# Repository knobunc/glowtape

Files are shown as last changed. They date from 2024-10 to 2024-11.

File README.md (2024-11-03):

# Glowtape

Glow-in-the-dark display, 64 pixels wide, and as long as the memory allows :)

Using a UV LED pixel illumination from the [Glowxels](http://glowxels.org)
project.

[Note: this is pretty much work in progress and not the final version.]

To build: get all dependencies (if you're using nix, or the nix package manager,
it is simplest, they are in shell.nix).
Mostly openscad for the case, rp2040 sdk and toolchain for the firmware,
[bdfont.data](https://github.com/hzeller/bdfont.data) to compactly encode fonts
used in the firmware and the [gcode-cli](https://github.com/hzeller/gcode-cli)
used in the [set-time utility](./set-time.sh).

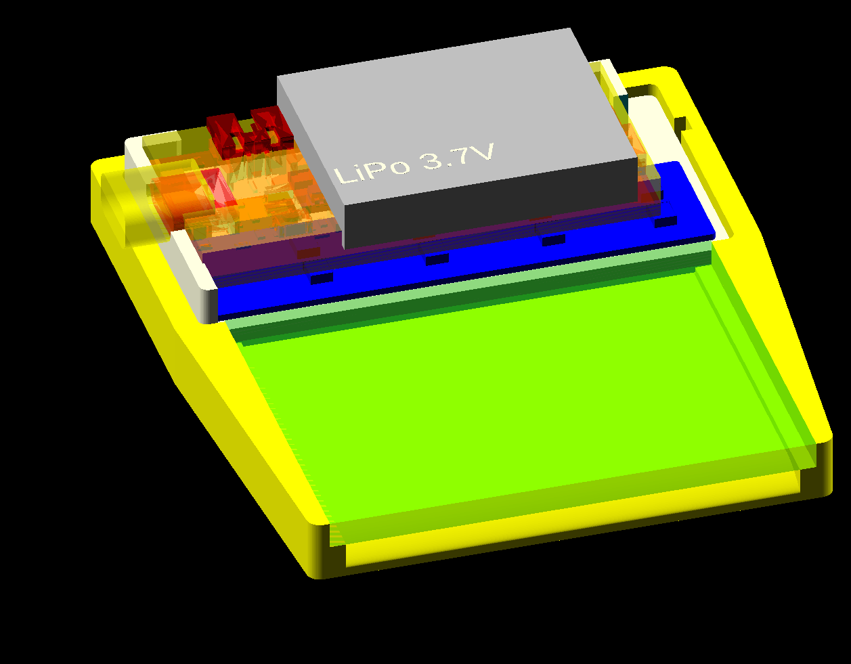
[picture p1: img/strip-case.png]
Render
  * [casing/](./casing/) for the OpenSCAD case 
  * [firmware/](./firmware/) contains the firmware.
  * [Gloxwls PCB](http://glowxels.org/). Check out the ['narrow'](https://github.com/hzeller/glowxels/tree/feature-20240902-narrow) feature branch.
  * [Encoder PCB](./pcb/encoder/) to pick up the encoder tape.
    Just type `make` to generate the fab files.
  * The sync-tape to be stuck to the back of the 50mm glow-in-dark
    tape: just `make` in the toplevel directory, it creates the PDF from
    the hand-written PostScript. Print on a high-resolution printer
    (e.g. 1200dpi) to minimize line-thickness variations due to aliasing.
  * Also some glow-in-dark tape that you can find in a hardware store, e.g.
    soemthing like [this](https://www.amazon.com/gp/product/B076BMQHXB)
    (no affiliation).

The RP2040 RTC does not remember its time after a reset (meh), so you need to
call the `./set-time.sh` script after a flash or reset/battery outage.

## Action shot

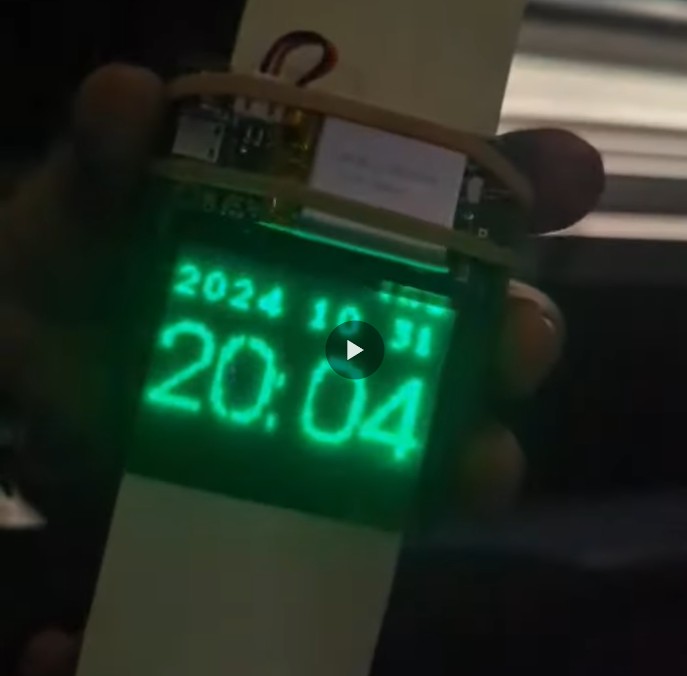
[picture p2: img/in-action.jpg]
Glow Watch (https://youtube.com/shorts/eKfHcU8QpuA)


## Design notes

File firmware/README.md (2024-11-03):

Firmware glowtape
=================

Makre sure you have all dependencies (on nix: get a nix-shell, otherwise get
pico SDK and compiler toolchain).

Then simply:

```
make
```

... and once Feather is connected with bootsel enabled

```
make flash
```

After the flash, the RP2040 RTC lost all time information, so you have to
set it again with

```
../set-time.sh
```

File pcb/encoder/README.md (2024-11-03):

Encoder PCB.

Note, this looks like one PCB, but you need to cut it in half in the middle at
the line.

Single-sided, so easy to etch at home.

For better contrast, I laser-cut a dark thin tape with two 0.4mm slots, 2mm
apart and taped on the photo transistor.

The strip-pattern is picked up with one photo transistor picking up a dark
strip, the other the light strip. When the tape is moved, the light conditions
swap. So the differntial pick-up makes it resilient to environment light
conditions as there does not need to be a fixed cut-off.

Choose resistors as needed; For `R9` LED, 82Ω was used. The `R1`, `R2` photo
transistor resistors, 2.7kΩ, `R5`: 10kΩ, and `R6`, which makes the whole
circuit a Schmitt Trigger for confident switch detection, somehing like 180kΩ.

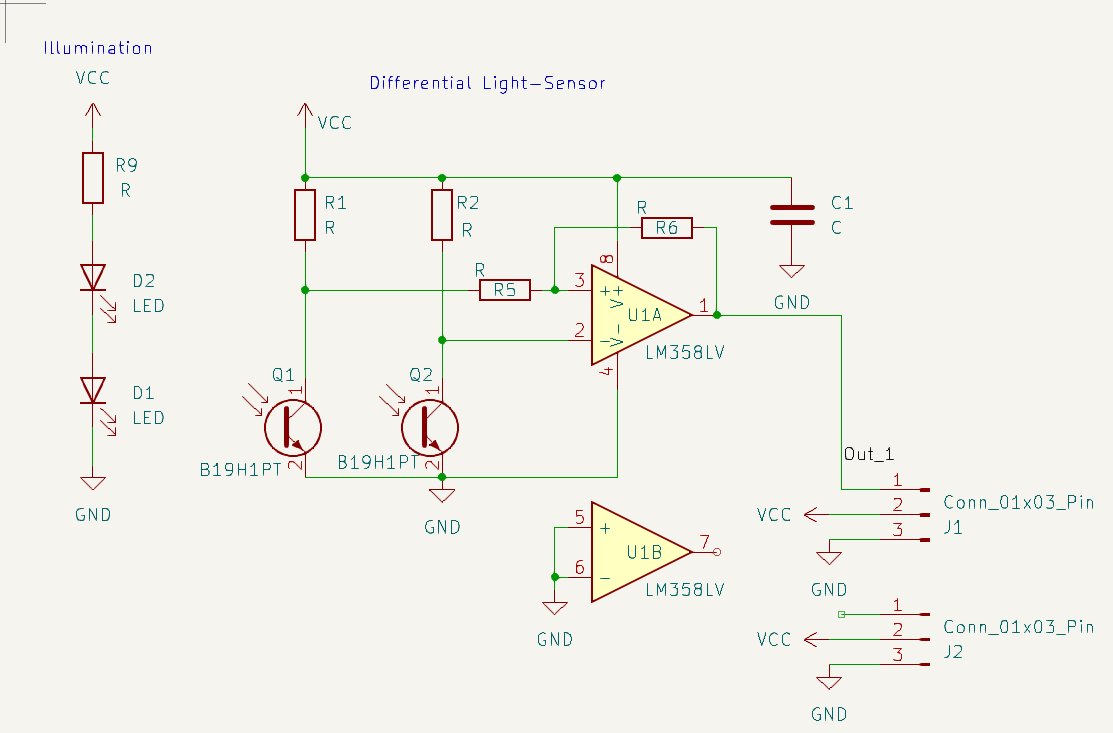
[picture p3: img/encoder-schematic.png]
Schematic


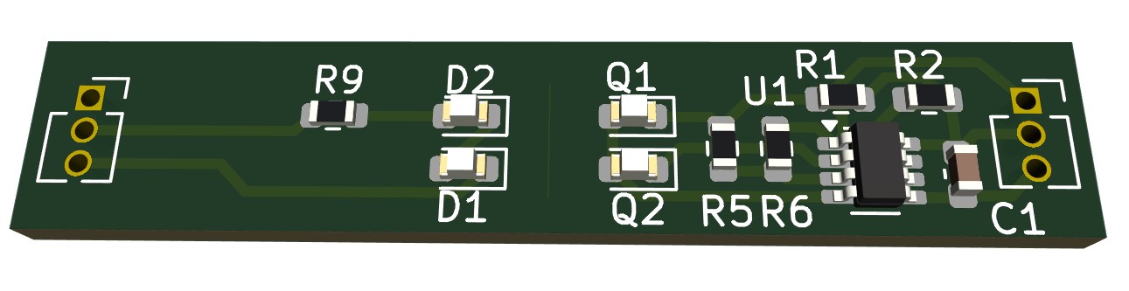
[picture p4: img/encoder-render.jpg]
Render


Here, a home-made isolation etch:

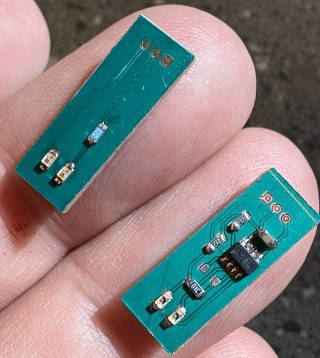
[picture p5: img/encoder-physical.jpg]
Physical


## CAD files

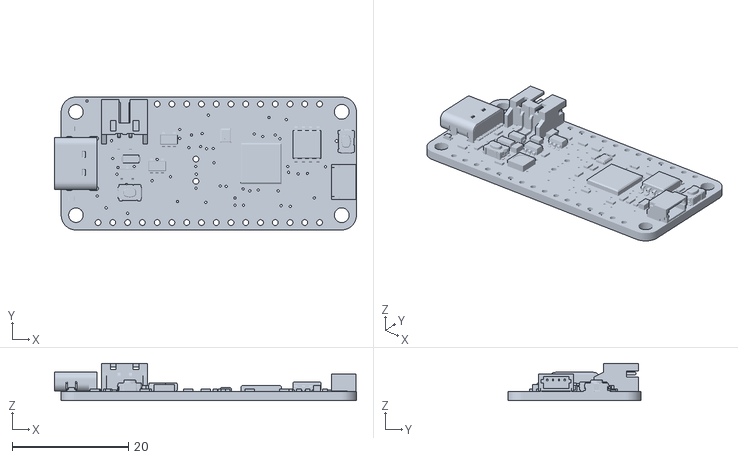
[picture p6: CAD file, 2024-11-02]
casing/Feather-rp2040.stl
51.9 x 22.9 x 6.37

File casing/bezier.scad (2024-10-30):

$fn=90;
e=0.01;

function _cubic_bazier_point(start, c1, c2, finish, t) =
  let (
    u = 1.0 - t,
    tt = t * t,
    uu = u * u
  )
  (u*uu) * start +
  3.0 * uu * t * c1 +
  3.0 * u * tt * c2 +
  (t*tt) * finish;

function cubic_bezier(start, c1, c2, finish, count=50) =
  [ for (t = [0 : 1/count : 1]) _cubic_bazier_point(start, c1, c2, finish, t) ];

module bezier_polygon(start, c1, c2, finish, count=100, visualize_cp=false) {
  polygon(cubic_bezier(start, c1, c2, finish, count));

  if (visualize_cp) {
    color("red") translate(c1) circle(r=0.2);
    color("green") translate(c2) circle(r=0.2);
  }
}

module viz_controlpoint(col, point, cp) {
  hull() {
    translate(point) circle(r=0.01);
    translate(cp) circle(r=0.01);
  }
  color(col) translate(cp) circle(r=0.1);
}

module viz_vertex(start, c1, c2, finish) {
  viz_controlpoint("red", start, c1);
  viz_controlpoint("green", finish, c2);
}

// One control point per point: Except for the last, they represent
// the first control-point after the point (the second control point is
// dereived from the _next_ segment, but pointing backwards, creating smooth
// curves.
module cubic_spline(points, cps,
		    extrude=-1, count=50,
		    show_controlpoints=false,
		    just_show_polygon=false) {
  effective_cps = (just_show_polygon || !cps) ? points : cps;
  assert(len(points) >= 2, "Need to have at least twp points");
  assert(len(points) == len(effective_cps),
	 "There needs one control point per point");
  second_to_last = len(points) - 1;
  list = [ for (i = [0:1:second_to_last-e])
      each cubic_bezier(points[i],
			effective_cps[i],
			i < second_to_last-1
			? points[i+1]-(effective_cps[i+1] - points[i+1])
			: effective_cps[i+1],
			points[i+1]) ];
  if (extrude > 0) {
    linear_extrude(height=extrude) polygon(list);
  } else {
    polygon(list);
  }

  if (show_controlpoints) {
    for (i = [0:1:second_to_last-e]) {
      viz_vertex(points[i], cps[i],
		 i < second_to_last-1
		 ? points[i+1]-(cps[i+1] - points[i+1])
		 : cps[i+1],
		 points[i+1]);
    }
  }
}

module place_along_curve(start, c1, c2, finish, at_fraction) {
  // Position
  pos = _cubic_bazier_point(start, c1, c2, finish, at_fraction);

  // Angle
  d0  = _cubic_bazier_point(start, c1, c2, finish, at_fraction - 0.01);
  d1  = _cubic_bazier_point(start, c1, c2, finish, at_fraction + 0.01);
  diff = d1 - d0;
  angle = atan2(diff.y, diff.x);

  translate([pos.x, pos.y, 0]) rotate([0, 0, angle]) children();
}


module test1() {
  cubic_spline(points=[  [0, 0], [1, 2], [3, 0]  ],
	       cps=[  [-1, 1], [2, 2], [4, 1]    ],
	       show_controlpoints=true);
}

module test2() {
  color("red") bezier_polygon([-1, 0], [0, 1], [3, 1], [2, 0]);
  place_along_curve([-1, 0], [0, 1], [3, 1], [2, 0], $t) {
    translate([-0.5, 0, 0]) cube([1, 1, 1]);
  }
}

test2();

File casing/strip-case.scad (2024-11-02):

// Note, this still needs cleanup.

use <bezier.scad>

$fn=60;
e=0.01;

top_len=59;
window_width=53.9;
window_elevate=1+e;

tape_width=50.3;
tape_thick=0.25;
extra_width=6;

track_thick=3;
acrylic_len=40;
front_frame=2;
illuminator_len=28 + front_frame;

track_len=illuminator_len + acrylic_len + 3;

module rounded_cube(w=20, h=10, thick=1, r=0.5) {
  r=(r <= 0) ? e : r;
  dx=w/2-r;
  dy=h/2-r;
  hull() {
    translate([+dx, -dy, 0]) cylinder(r=r, h=thick);
    translate([+dx, +dy, 0]) cylinder(r=r, h=thick);
    translate([-dx, -dy, 0]) cylinder(r=r, h=thick);
    translate([-dx, +dy, 0]) cylinder(r=r, h=thick);
  }
}

module pocket_cube(c, r=0.3) {
  cube(c);
  cylinder(r=r, h=c[2]);
  translate([c[0], 0, 0]) cylinder(r=r, h=c[2]);
  translate([c[0], c[1], 0]) cylinder(r=r, h=c[2]);
  translate([0, c[1], 0]) cylinder(r=r, h=c[2]);
}

module usb() {
  rotate([0, -90, 0]) hull() {  // USB extension
    cylinder(r=1.65, h=10);
    translate([0, 6, 0]) cylinder(r=1.65, h=10);
  }
}

module rp2040_simple() {
  translate([-50.8/2, 0, 0]) cube([50.8, 23, 4.8]);
  hull() {
    translate([-22, 8.4, 3.1]) usb();  // actual location
    translate([-22, 8.4, 5]) usb();    // punch-out help
  }
}

module rp2040_board(extra=0) {
  render() color("#ff000070") translate([-50.8/2, 0, 0]) {
    cube([50.8, 23, 1.6]);  // board thicken
    if (false) translate([2, 8.4, 3.28]) rotate([0, -90, 0]) hull() {  // USB extension
      cylinder(r=1.65, h=10);
      translate([0, 6, 0]) cylinder(r=1.65, h=10);
    }
    difference() {
      import("Feather-rp2040.stl");
      //translate([6.5, 14, 3]) cube([9, 10, 7]);  // battery connector.
    }
  }
}

module glowxel_pcb() {
  color("#0000ffff") {
    translate([-75.6, 39+14.3, 0]) import("glowxels-small.stl");
    translate([0, 14.4/2-0.2, 0]) color("red") rounded_cube(55.6, 14.4, 3);
  }
}

module encoder_board(w, h) {
  color("purple") {
    translate([-w/2, -h/2, 0]) cube([w, h, 3]);
    translate([-6.3, 0, -1.8]) cylinder(r=2.5, h=2);  // viewport
    translate([w/2-3, -h/2, -2]) cube([3, h, 3]);  // Glue joint
    translate([w/2, -(h-1)/2, 0]) cube([2, h-1, 3]);  // Cable
  }
}

module sensor_locator() {
  translate([-3, 20, 0]) children();
}

module strip_led_light() {
  encoder_board(19.1, 6.8); // IR LED illumination
}

module strip_sensor() {
  w=19.7;
  h=7.4;
  translate([-w/2, -h/2, -2.7]) pocket_cube([w, h, 3]);  // hollow
  // bottom retainer
  translate([-(w-1)/2, -(h-1)/2, -track_thick-e]) cube([w-1, h-1, track_thick]);
  translate([w/2-e, -(h-1)/2, -1.5]) cube([2, h-1, 3]);  // Cable extract
  fudge_len=tape_width/2-1;
  translate([w/2-e, -2.5/2, -1]) cube([fudge_len, 2.5, 6]);  // Cable channel
}

module battery() {
  color("silver") cube([32.5, 25.5, 5.7]);
  translate([0.5, 4, 0]) linear_extrude(height=5.7+e) text("LiPo 3.7V", size=3);
}

module window(punch=0) {
  len=acrylic_len + punch;
  color("#00ff0040") translate([-window_width/2, -len, 0]) {
    cube([window_width, len, 3+punch]);
  }
}

module pcb_arrangement() {
  translate([0, front_frame, 0]) {
    translate([0.3, 0, 0.25]) glowxel_pcb();
    sensor_locator() translate([0, 0, +0.5]) strip_led_light();
    //sensor_locator() translate([0, 0, -tape_thick]) strip_sensor();
    translate([-2.5, 3, 4.5]) {
      rp2040_board();
      color("#ffff0070") rp2040_simple();
      translate([-10, -1, 3]) battery();
    }
  }
}

module track_bottom(l=0, r=track_len, b=-track_thick) {
  turn=b+1;
  cubic_spline(points=[  [l+0, b],   // start edge. +0=sharp edge
			 [l, b+1], [l+5, 0],

			 [r-5, 0], [r, b+1],
			 [r-0, b]
		      ],

	       cps = [   [l, b],
			 [l, turn+0.5], [l+5+2, 0],

			 [r-5+2, 0], [r, turn-0.5],
			 [r, b]
		     ],
	       extrude=tape_width,
	       show_controlpoints=false,
	       just_show_polygon=false);
}

module base_case_bottom(len=top_len, back=illuminator_len, height=2.5, extra=0) {
  translate([0, back/2, 0]) rounded_cube(len+extra, back+extra, height, r=1);
}

module base_case(len=top_len) {
  back=illuminator_len;
  render() translate([0, front_frame, 0]) difference() {
    intersection() {
      union() {
	translate([0, -front_frame, 0]) base_case_bottom(len, back);

	// Center rests
	translate([-20-1, 14.5, 0]) cube([7, 4, 5]);
	translate([+20-7-3, 14.5, 0]) cube([7, 4, 5]);

	// Side holders
	translate([-5, 0, 0]) translate([len/2-5, back-8-2, 0]) cube([5, 8, 8]);
	translate([-len/2, back-13.5-2, 0]) cube([6, 13.5, 8]);
	translate([-len/2, -front_frame, 0]) cube([1.8, illuminator_len, 8]);
	//translate([-len/2, illuminator_len-front_frame-1.5, 0]) cube([len, 1.5, 8]);
      }
      translate([0, -front_frame, 0]) base_case_bottom(len, back, 20);
    }
    translate([0, -front_frame, 0]) pcb_arrangement();
    translate([0, 6.6, -3]) {
      rounded_cube(w=54, h=9, r=2.5, thick=6);  // UV-window
    }
    translate([0, -1, 2.6]) sensor_locator() cube([60, 2, 10]);
  }
}

module ear() {
  cylinder(r=2, h=0.2);
}

module base_case_print() {
  base_case();
}

module side_wall(wall_height=4) {
  r=1.5;
  h=wall_height + track_thick;
  // The wider part for the illuminator.
  extra_wide=(top_len - tape_width)/2;

  hull() {
    translate([0, 0, -track_thick]) cube([e, track_len, h]);

    translate([r+1, r, -track_thick]) cylinder(r=r, h=h);
    translate([r, track_len-r, -track_thick]) cylinder(r=r, h=h);

    translate([r+extra_wide, acrylic_len, -track_thick]) cylinder(r=r, h=h);
    translate([r+extra_wide, track_len-r, -track_thick]) cylinder(r=r, h=h);
  }
}

module track_frame() {
  translate([-tape_width/2, -acrylic_len, 0]) {
    rotate([0, 0, 90]) rotate([90, 0, 0])  track_bottom();
  }
  translate([tape_width/2, -acrylic_len, 0]) side_wall();
  translate([-tape_width/2, -acrylic_len, 0]) scale([-1, 1, 1]) side_wall();
}

module track() {
  difference() {
    track_frame();
    translate([0, 0, tape_thick]) base_case_bottom(height=10, extra=0.4);
    translate([0, 0, window_elevate]) window(punch=1);
    sensor_locator() translate([0, front_frame, 0]) strip_sensor();
  }
}

module assembly() {
  color("yellow") track();
  translate([0, 0, tape_thick]) {
    base_case_print();
    pcb_arrangement();
  }
  translate([0, 0, window_elevate]) window();
}

assembly();

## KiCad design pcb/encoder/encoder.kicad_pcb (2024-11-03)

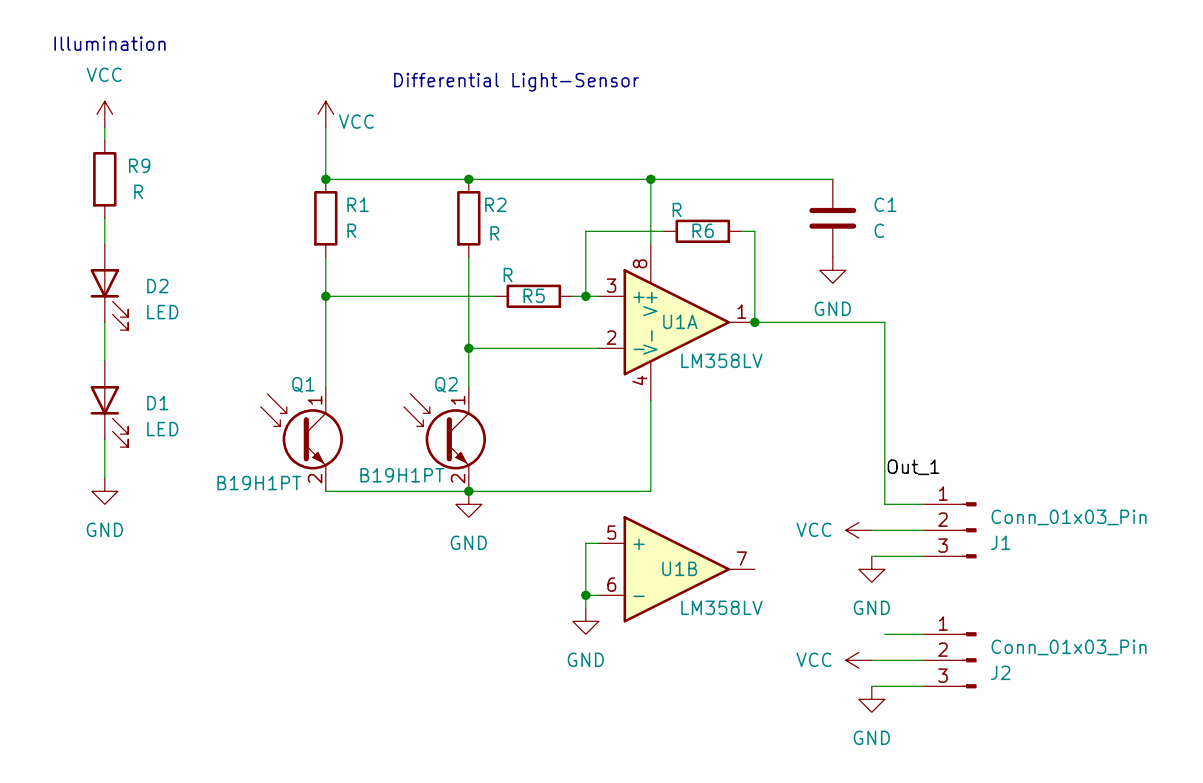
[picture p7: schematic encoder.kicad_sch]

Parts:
C1: C; C_0603_1608Metric
D1, D2: LED; LED_0603_1608Metric
J1, J2: Conn_01x03_Pin; PinSocket_1x03_P1.27mm_Vertical
Q1, Q2: B19H1PT; LED_0603_1608Metric
R1, R2, R5, R6, R9: R; R_0603_1608Metric
U1: LM358LV; SOT-23-8

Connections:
/Out_1: J1.1, R6.2, U1.1
GND: C1.2, D1.1 (K), J1.3, J2.3, Q1.2 (E), Q2.2 (E), U1.4 (V-), U1.5 (+), U1.6 (-)
unnamed: D1.2 (A), D2.1 (K)
unnamed: D2.2 (A), R9.2
unnamed: Q1.1 (C), R1.2, R5.1
unnamed: Q2.1 (C), R2.2, U1.2 (-)
unnamed: R5.2, R6.1, U1.3 (+)
VCC: C1.1, J1.2, J2.2, R1.1, R2.1, R9.1, U1.8 (V+)

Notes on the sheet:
Differential Light-Sensor
Illumination

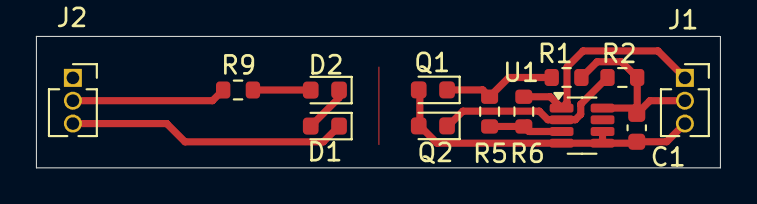
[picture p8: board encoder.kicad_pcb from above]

Board: 2 copper layers, 38.0 x 7.3 mm, 13 parts (0 on the bottom side), 8 nets.

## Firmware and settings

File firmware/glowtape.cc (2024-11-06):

#include <pico/types.h>

#include <cstdio>

#include "bdfont-support.h"
#include "button-counter.h"
#include "frame-printer.h"
#include "hardware/rtc.h"
#include "line-reader.h"
#include "strip-encoder.h"

// Generated font data
#include "font-6x9.h"
#include "font-large.h"
#include "font-message.h"
#include "font-timetext.h"

// Some demo bitmap content
#include "bitmap-contents.h"

// Time a single line is flashing the 405nm LEDs.
constexpr uint16_t kFlashTimeMillis = 5;

// GPIO where the input button lives. The Feather board has the BOOTSEL button
// connected to this GPIO.
constexpr int kButtonPin = 4;

constexpr int kSpiTxPin = 11;  // TX1, 10=sck1, 9=CS1

// A simple wrapper to emit bdfont text to out FramePrinter.
static void WriteText(FramePrinter *out, const struct FontData *font, int xpos,
                      int ypos, const char *print_text,
                      bool right_aligned = false, int extra_space = 0) {
  if (right_aligned) {
    for (const char *txt = print_text; *txt; ++txt) {
      auto g = bdfont_find_glyph(font, *txt);
      if (g) xpos -= g->width;
      xpos -= extra_space;
    }
  }
  for (const char *txt = print_text; *txt; ++txt) {
    int dx = 0;
    xpos += BDFONT_EMIT_GLYPH(
        font, *txt, false, { dx = 0; },
        {
          for (int i = 0; i < 8; ++i) {
            out->SetPixel(xpos + dx, stripe * 8 + ypos + i, b & (1 << i));
          }
          ++dx;
        },
        {});
    xpos += extra_space;
  }
}

void DrawTime(FramePrinter *out) {
  datetime_t now{};
  const bool time_valid = rtc_get_datetime(&now);
  if (!time_valid) {
    // RTC of rp2040 is a bit annoying, its content does not survive
    // resets. To be set with the set-time.sh script.
    WriteText(out, &font_6x9, 2, 0, "Set Time!");
    return;
  }
  const char *weekday = "-";
  switch (now.dotw) {
    case 0: weekday = "Sunday"; break;
    case 1: weekday = "Monday"; break;
    case 2: weekday = "Tuesday"; break;
    case 3: weekday = "Wednesday"; break;
    case 4: weekday = "Thursday"; break;
    case 5: weekday = "Friday"; break;
    case 6: weekday = "Saturday"; break;
  }
  WriteText(out, &font_6x9, 62, 0, weekday, true);

  char buffer[32];
  snprintf(buffer, sizeof(buffer), "%4d-%02d-%02d", now.year, now.month,
           now.day);
  WriteText(out, &font_6x9, 2, 10, buffer);

  snprintf(buffer, sizeof(buffer), "%02d:%02d", now.hour, now.min);
  WriteText(out, &font_timetext, 2, 22, buffer);
}

// Create content, derived from number of button presses before.
void CreateContent(FramePrinter *out, int what_content) {
  enum Content {
    kTime,  // Default: no button presses
    kName,
    kJollyWrencher,
    kSupercon,
    kProject,
  };

  out->StartNewImage(ScreenAspect::kAlongWidth);

  if (what_content == kJollyWrencher) {
    for (uint64_t row : kJollyWrencherBitmap) {
      out->push_back(row);
    }
    return;
  }

  if (what_content == kName) {
    WriteText(out, &font_message, 2, 0, "Henner", false, 2);
    WriteText(out, &font_message, 62, 15, "Zeller", true, 2);
    return;
  }

  if (what_content == kSupercon) {
    out->StartNewImage(ScreenAspect::kAlongLength);
    WriteText(out, &font_large, 0, 8, "Supercon 8");
    return;
  }

  if (what_content == kProject) {
    for (uint64_t row : kProjectQRBitmap) {
      out->push_back(row);
    }
    return;
  }

  // None of the above ? Ok, time then.
  DrawTime(out);
}

static void TimeSetter(const char *value) {
  int year, month, day, hour, min, sec, day_of_week;
  int count = sscanf(value, "%d-%d-%d %d:%d:%d %d\n", &year, &month, &day,
                     &hour, &min, &sec, &day_of_week);
  if (count != 7) {
    printf("Error: expected YYYY-MM-DD hh:mm:ss dow\nDow: 0=SUN ... 6=SAT\n");
    return;
  }

  const datetime_t now = {
      .year = (int16_t)year,
      .month = (int8_t)month,
      .day = (int8_t)day,
      .dotw = (int8_t)day_of_week,
      .hour = (int8_t)hour,
      .min = (int8_t)min,
      .sec = (int8_t)sec,
  };
  if (rtc_set_datetime(&now)) {
    printf("\nOK\n");
  } else {
    printf("\nERROR\n");
  }
}

int main() {
  stdio_init_all();  // Init serial, such as uart or usb
  rtc_init();

  // Peripherals
  LineReader<256> process_serial(&TimeSetter);
  StripEncoder encoder;
  ButtonCounter button(kButtonPin);
  FramePrinter printer(kSpiTxPin, spi1);  // 0.8mm * 1024 ≈ 82cm

  int16_t fast_steps = 0;
  int16_t forward_steps = 0;
  for (;;) {
    process_serial.Poll();
    button.Poll();

    switch (encoder.Poll()) {
      case StripEncoder::Result::kFirstTick:
        CreateContent(&printer, button.count());
        printer.SendStart();
        fast_steps = forward_steps = 0;
        button.Reset();
        break;

      case StripEncoder::Result::kFastTick:
        ++fast_steps;  // If we see more than 4 of these, stop sending anything.
        if (forward_steps > 4 && fast_steps < 4 && printer.SendNext()) {
          printer.LightFlash(kFlashTimeMillis);
        }
        break;

      case StripEncoder::Result::kTick:
        ++forward_steps;  // Want to see first if consistent stream of ticks.
        if (forward_steps > 4 && fast_steps < 4 && printer.SendNext()) {
          printer.LightFlash(kFlashTimeMillis);
        }
        break;

      case StripEncoder::Result::kNoTick:
        // Nothing to do.
        break;
    }
  }
}

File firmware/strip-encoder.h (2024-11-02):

#ifndef STRIP_ENCODER_H
#define STRIP_ENCODER_H

#include <cstdint>

#include "hardware/gpio.h"
#include "pico/time.h"

class StripEncoder {
  static constexpr int kLEDPin = 13;  // On Feather board.
  static constexpr int kLineEncoderIn = 7;
  static constexpr int64_t kTimeoutUsec = 500'000;
  static constexpr int64_t kFastTickUsec = 7'000;

 public:
  enum class Result {
    kFirstTick,  // First tick after idle for a while
    kNoTick,     // No change detected
    kFastTick,   // Tick since last seen, but was very fast.
    kTick,       // change since last
  };

  StripEncoder() {
    gpio_init(kLineEncoderIn);
    gpio_set_dir(kLineEncoderIn, GPIO_IN);

    // Debug output.
    gpio_init(kLEDPin);
    gpio_set_dir(kLEDPin, GPIO_OUT);
  }

  // Needs to be called regularly.
  Result Poll() {
    const bool current_read = gpio_get(kLineEncoderIn);
    const bool edge_detected = current_read && !last_read_;
    last_read_ = current_read;

    if (!edge_detected) return Result::kNoTick;

    const absolute_time_t this_tick_time = get_absolute_time();
    const int64_t usec_diff =
        absolute_time_diff_us(last_tick_time_, this_tick_time);
    last_tick_time_ = this_tick_time;

    if (usec_diff < kFastTickUsec) {
      gpio_put(kLEDPin, true);
      return Result::kFastTick;
    }
    gpio_put(kLEDPin, false);
    if (usec_diff > kTimeoutUsec) {
      return Result::kFirstTick;
    }
    return Result::kTick;
  }

 private:
  bool last_read_ = false;
  absolute_time_t last_tick_time_{};
};
#endif

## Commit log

2024-10-18 Playing with optical pickup of sync-stripes.
    [encoder.kicad_pcb, encoder.kicad_sch]
2024-10-28 Update to separate pick-up and illumination.
    [encoder.kicad_pcb, encoder.kicad_sch]
2024-10-28 Switch board to feather.
2024-10-29 Read line encoder.
2024-10-30 case, WIP
    [bezier.scad, strip-case.scad]
2024-10-30 Let rp2040 sit flat.
    That also allows to wedge the board in a bracket.
    [strip-case.scad]
2024-10-30 Tiny adaption.
    [strip-case.scad]
2024-10-31 More space for sensor board.
    [strip-case.scad]
2024-10-31 Move encoder pin to gpio7
2024-10-31 Basic text support. Switch content on button.
2024-10-31 Print out actual time.
2024-11-01 More space between letters, avoid dead pixels.
    [glowtape.cc]
2024-11-01 Name after first button press.
2024-11-02 Add 3D board view.
    [Feather-rp2040.stl]
2024-11-02 Update README.
    [strip-case.scad]
2024-11-02 Document sync-tape print.
2024-11-02 Generate bdfont support from datagen.
    Also: simplify serial line reader and prevent buffer overflow.
    [frame-printer.h, glowtape.cc]
2024-11-03 Some README refinements.
    [encoder.kicad_pcb, encoder.kicad_sch]
2024-11-06 Use long name weekdays.
    With some dead pixels fixed, they look now nice.
    [glowtape.cc]
